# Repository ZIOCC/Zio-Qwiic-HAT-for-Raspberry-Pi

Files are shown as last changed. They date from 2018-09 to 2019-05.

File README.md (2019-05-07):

# Zio Qwiic HAT for Raspberry Pi

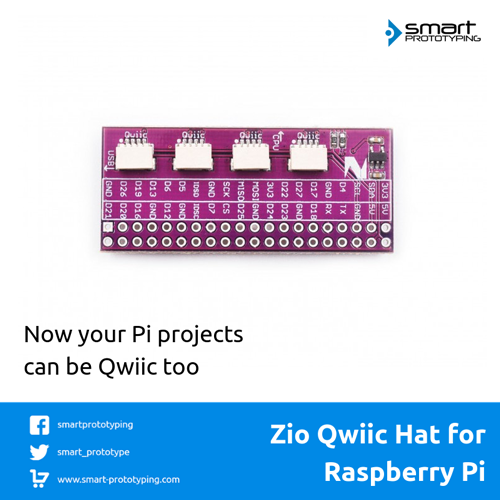
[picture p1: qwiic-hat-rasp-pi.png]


> This product can be available for purchase [here](https://www.smart-prototyping.com/Zio-Qwiic-Hat-for-Raspberry-Pi).

#### Description

We will not be satisfied if you cannot use Qwiic system on Raspberry Pi in a Qwiic way, this is why we made this Qwiic Hat for Raspberry Pi. It has a standard shield design like other Raspberry Pi add-ons.

Our Qwiic Hat has eight Qwiic connectors that connect to Raspberry Pi’s I2C pins, so they all have the same I2C address.  We also add the original Pi’s ’pin names on the board for your reference.

We have two different version 2x20 female headers to offer, long pin and short pin (optional). With the long pin header, you can stack up against other Pi add-on shield. Please note that the 2x20 pin header is not pre-soldered.

#### Specification

* Board Dimension: 22.3x51.0mm
* Weight: 11.1g
* Long pins female header’s pin length: 12.2mm

#### Links

* [PCB source file and schematic](https://github.com/ZIOCC/Zio-Qwiic-HAT-for-Raspberry-Pi)

> ###### About Zio
> Zio is a new line of open sourced, compact, and grid layout boards, fully integrated for Arduino and Qwiic ecosystem. Designed ideally for wearables, robotics, small-space limitations or other on the go projects. Check out other awesome Zio products [here](https://www.smart-prototyping.com/Zio).

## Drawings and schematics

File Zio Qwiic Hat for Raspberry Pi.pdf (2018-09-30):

1 | 2 | 3 | 4

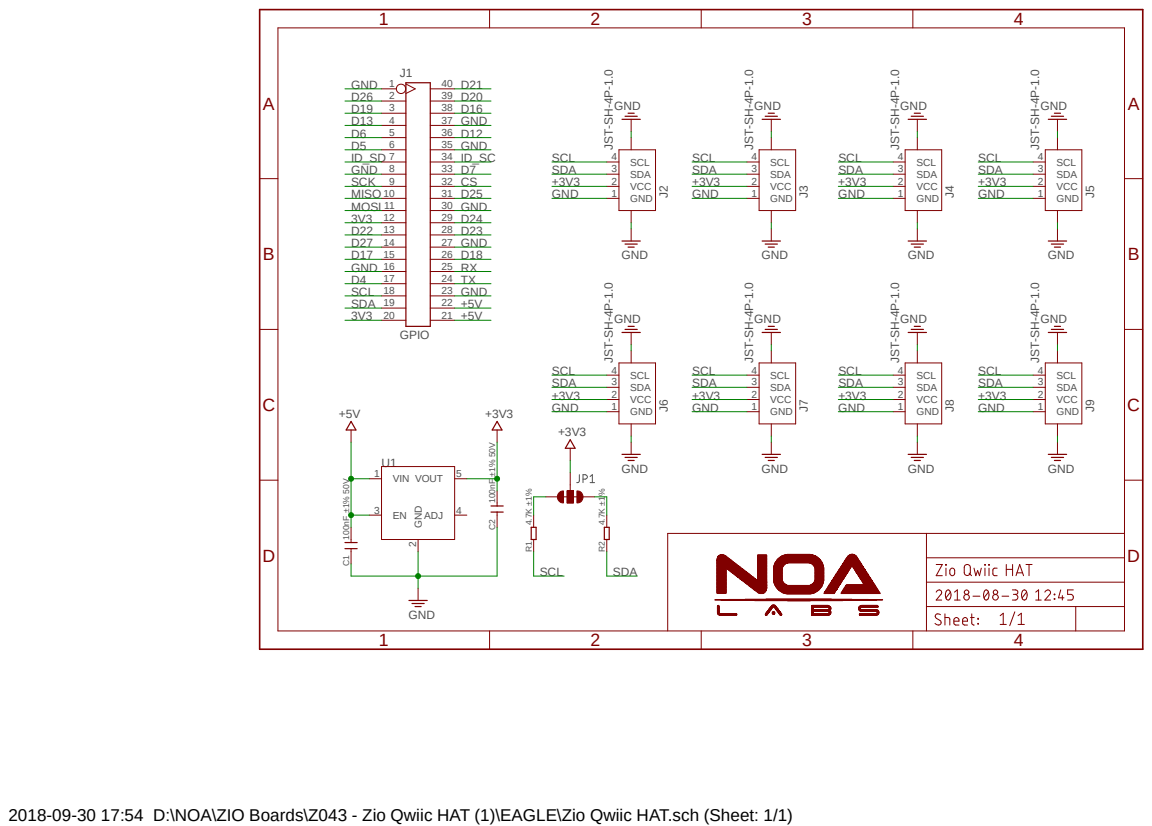
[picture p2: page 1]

2018-09-30 17:54 D:\NOA\ZIO Boards\Z043 - Zio Qwiic HAT (1)\EAGLE\Zio Qwiic HAT.sch (Sheet: 1/1)

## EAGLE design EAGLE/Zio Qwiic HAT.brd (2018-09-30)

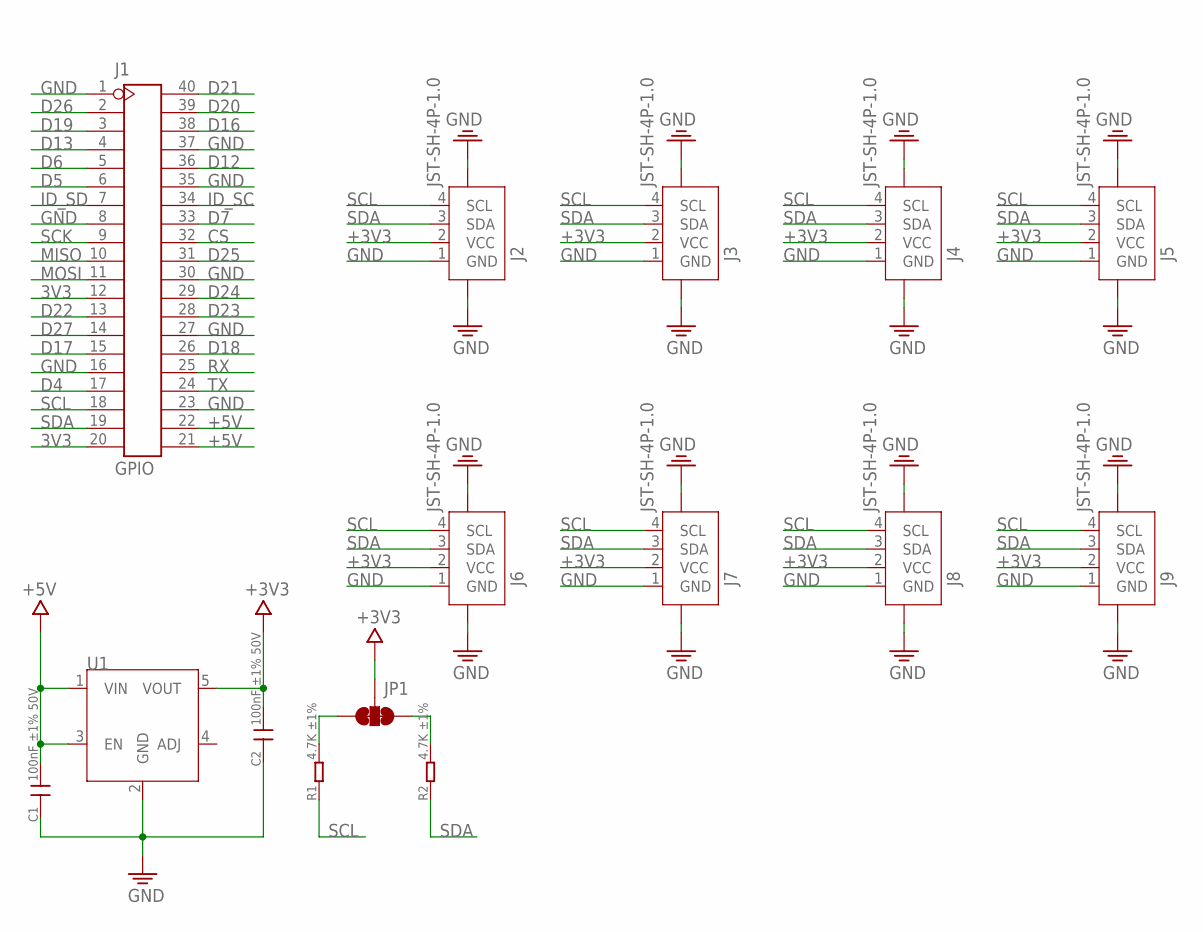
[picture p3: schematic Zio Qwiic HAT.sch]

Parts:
C1, C2: 100nF ±1% 50V; C0603
J1: GPIO; 2X20P_2.54
J2, J3, J4, J5, J6, J7, J8, J9: JST-SH-4P-1.0; JST-SH-4P
JP1: SMT-JUMPER_3_2-NC_TRACE
R1, R2: 4.7K ±1%; R0603
U1: AP2112; SOT23-5

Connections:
3V3: J1.12, J1.20
+3V3: C2.2, J2.2 (VCC), J3.2 (VCC), J4.2 (VCC), J5.2 (VCC), J6.2 (VCC), J7.2 (VCC), J8.2 (VCC), J9.2 (VCC), JP1.2, U1.5 (VOUT)
+5V: C1.2, J1.21, J1.22, U1.1 (VIN), U1.3 (EN)
CS: J1.32
D4: J1.17
D5: J1.6
D6: J1.5
D7: J1.33
D12: J1.36
D13: J1.4
D16: J1.38
D17: J1.15
D18: J1.26
D19: J1.3
D20: J1.39
D21: J1.40
D22: J1.13
D23: J1.28
D24: J1.29
D25: J1.31
D26: J1.2
D27: J1.14
GND: C1.1, C2.1, J1.1, J1.8, J1.16, J1.23, J1.27, J1.30, J1.35, J1.37, J2.1 (GND), J2.NC1 (5), J2.NC2 (6), J3.1 (GND), J3.NC1 (5), J3.NC2 (6), J4.1 (GND), J4.NC1 (5), J4.NC2 (6), J5.1 (GND), J5.NC1 (5), J5.NC2 (6), J6.1 (GND), J6.NC1 (5), J6.NC2 (6), J7.1 (GND), J7.NC1 (5), J7.NC2 (6), J8.1 (GND), J8.NC1 (5), J8.NC2 (6), J9.1 (GND), J9.NC1 (5), J9.NC2 (6), U1.2 (GND)
ID_SC: J1.34
ID_SD: J1.7
MISO: J1.10
MOSI: J1.11
unnamed: JP1.3, R1.2
unnamed: JP1.1, R2.2
RX: J1.25
SCK: J1.9
SCL: J1.18, J2.4 (SCL), J3.4 (SCL), J4.4 (SCL), J5.4 (SCL), J6.4 (SCL), J7.4 (SCL), J8.4 (SCL), J9.4 (SCL), R1.1
SDA: J1.19, J2.3 (SDA), J3.3 (SDA), J4.3 (SDA), J5.3 (SDA), J6.3 (SDA), J7.3 (SDA), J8.3 (SDA), J9.3 (SDA), R2.1
TX: J1.24

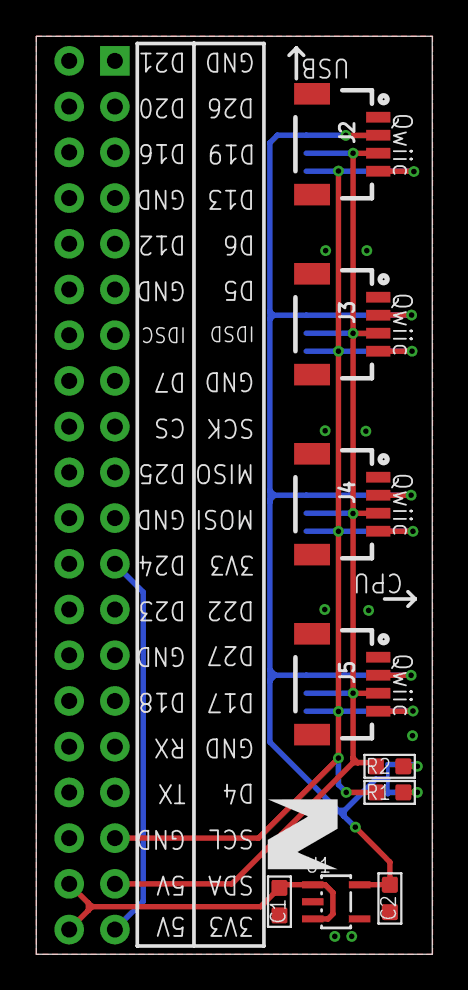
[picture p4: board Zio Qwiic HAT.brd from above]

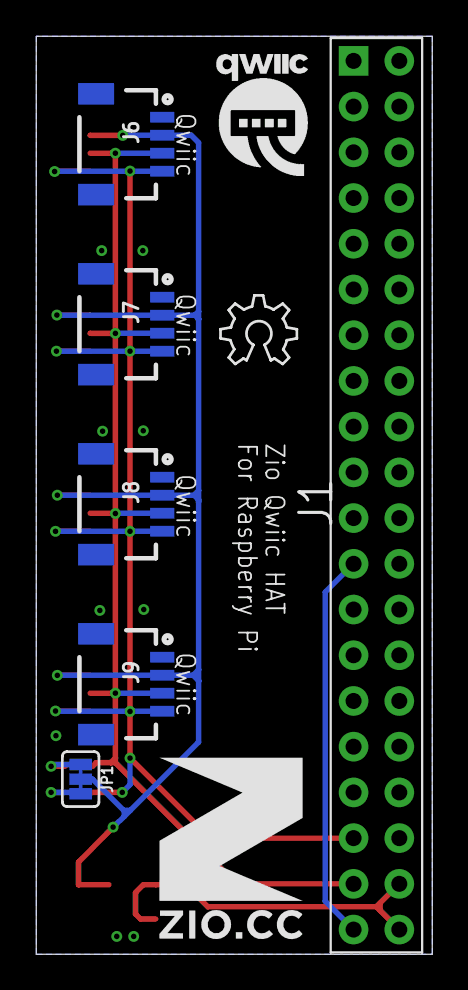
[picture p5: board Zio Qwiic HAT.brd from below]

Board: 2 copper layers, 22.0 x 51.0 mm, 19 parts (9 on the bottom side), 8 nets.

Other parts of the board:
U$4: 10MM
U$5: QWIIC-LOGO-MEDIUM
U$6: OSHW_6X150_NOTEXT
U$7: 6MM
